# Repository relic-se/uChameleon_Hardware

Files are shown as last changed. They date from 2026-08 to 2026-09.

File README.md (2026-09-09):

# μChameleon Hardware
Digital guitar effects pedal designed around the Raspberry Pi Pico 2 and the TLC320AIC3204.

| 3D Enclosure | PCB Top | PCB Bottom |
|-|-|-|
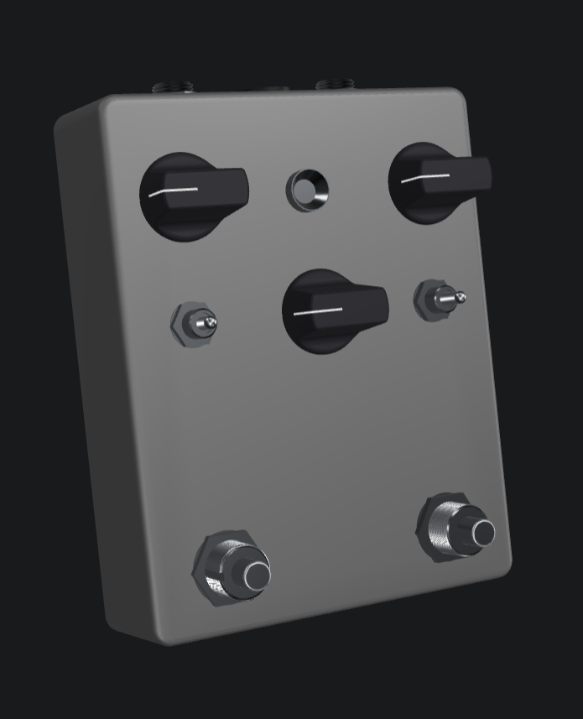
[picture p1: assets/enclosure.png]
3D rendering of μChameleon assembled enclosure
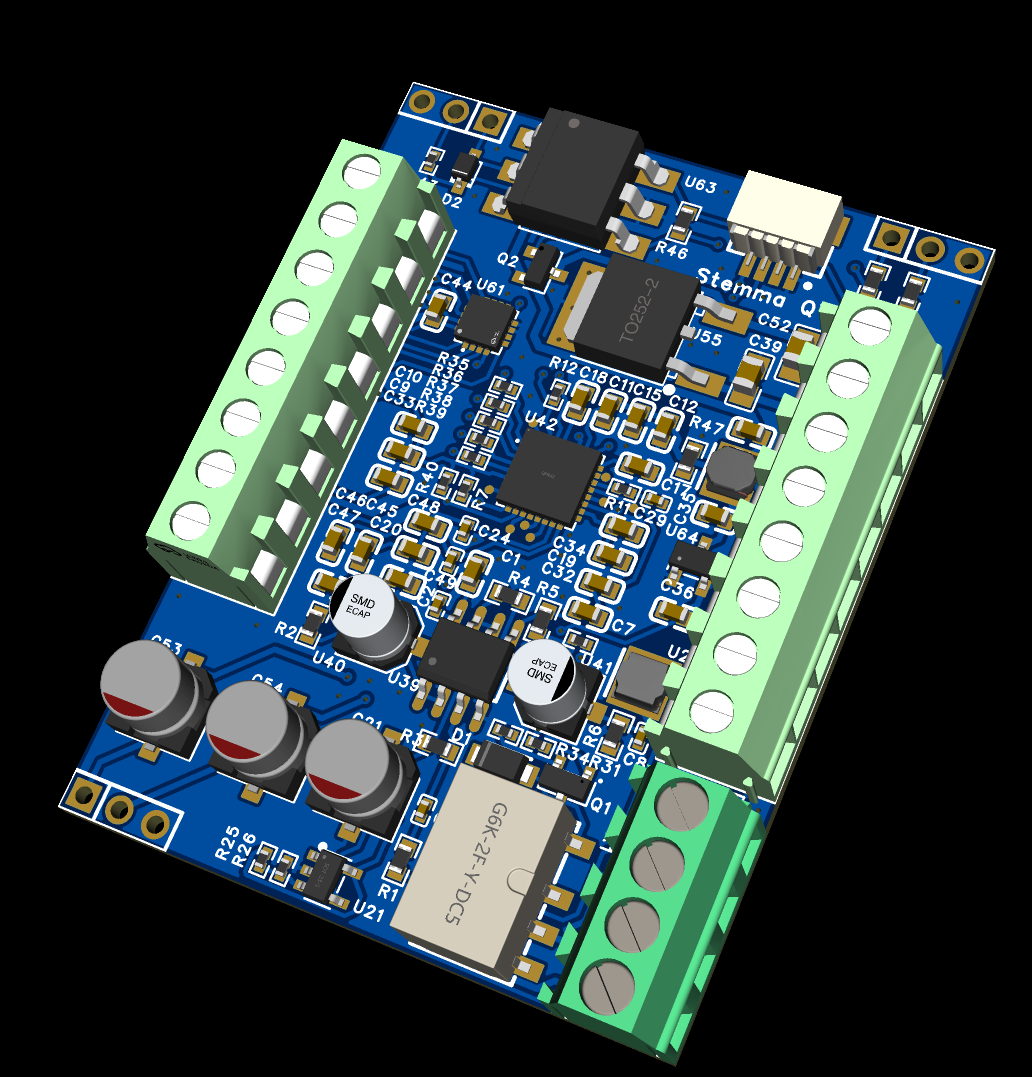
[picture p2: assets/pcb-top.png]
3D rendering of the top of the μChameleon PCB
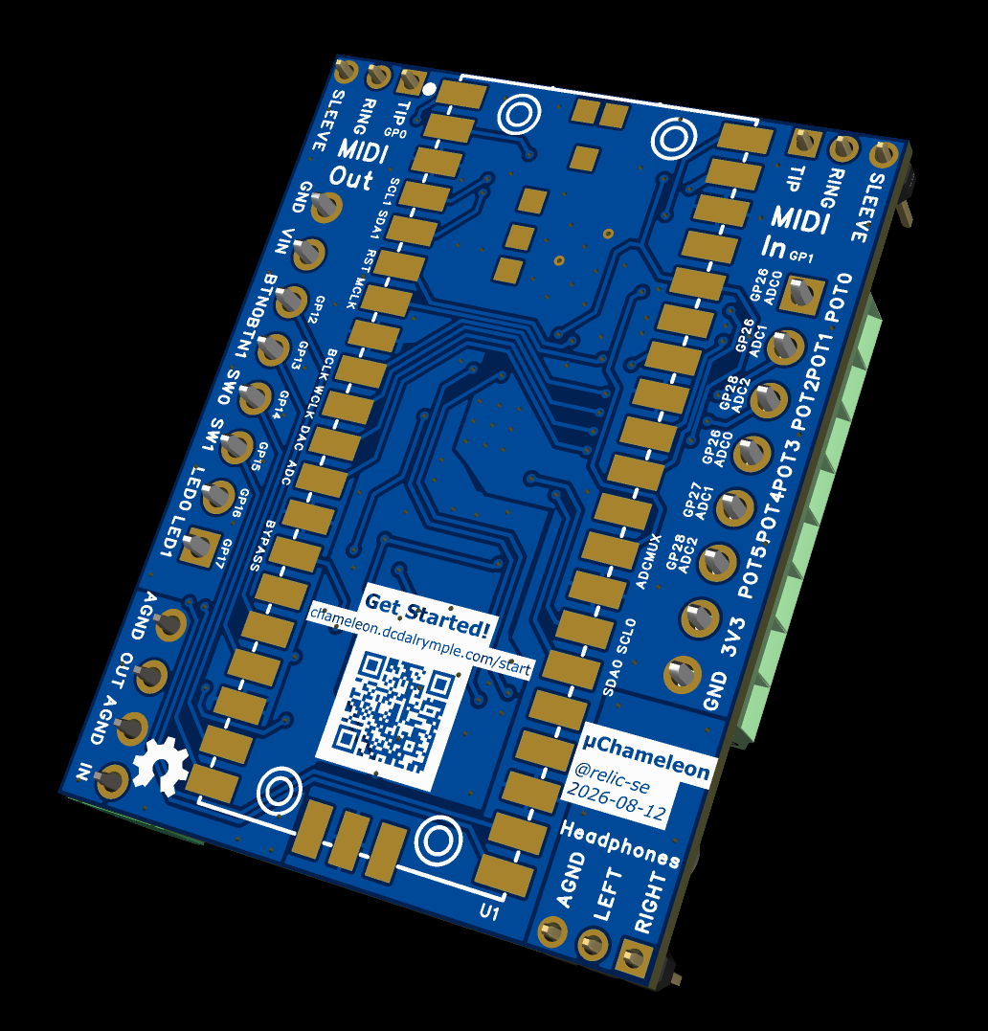
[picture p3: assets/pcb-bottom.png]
3D rendering of the bottom of the μChameleon PCB without a Raspberry Pi Pico 2
|  |  | 

## Software

- [CircuitPython Firmware](https://github.com/relic-se/uChameleon_CircuitPython)
- Arduino Firmware _(planned)_

## GPIO Configuration

The following table defines the pin configuration for the Raspberry Pi Pico (1 or 2) device.

| Pin | Function | Name | Description |
|-----|---|---|---|
| GP0 | UART | MIDI_OUT | MIDI output at 31.25 kHz |
| GP1 | UART | MIDI_IN | Opto-isolated MIDI input at 31.25 kHz |
| GP2 | I2C | SDA1 | STEMMA QT data input/output |
| GP3 | I2C | SCL1 | STEMMA QT clock |
| GP4 | GPIO | RST | Codec reset output _(active low)_ |
| GP5 | I2S | MCLK | Master clock |
| GP6 | I2S | BCLK | Bit clock |
| GP7 | I2S | WCLK | Word clock |
| GP8 | I2S | DIN | Digital audio data (DAC) |
| GP9 | I2S | DOUT | Digital audio data (ADC) |
| GP10 | GPIO | BYPASS | Preamp true bypass output _(active low)_ |
| GP11 | _Unused_ | | |
| GP12 | GPIO | BTN0 | Left footswitch button input |
| GP13 | GPIO | BTN1 | Right footswitch button input |
| GP14 | GPIO | SW0 | Left toggle switch input |
| GP15 | GPIO | SW1 | Right toggle switch input |
| GP16 | PWM | LED0 | Primary led indicator output |
| GP17 | PWM | LED1 | Secondary led indicator output |
| GP18 | _Unused_ | | |
| GP19 | _Unused_ | | |
| GP20 | I2C | SDA0 | Codec control data input/output |
| GP21 | I2C | SCL0 | Codec control clock |
| GP22 | GPIO | MUX | ADC multiplexer bank switch output _(active high)_ |
| GP26 | ADC | ADC0 | Input for POT0/3 |
| GP27 | ADC | ADC1 | Input for POT1/4 |
| GP28 | ADC | ADC2 | Input for POT2/5 |

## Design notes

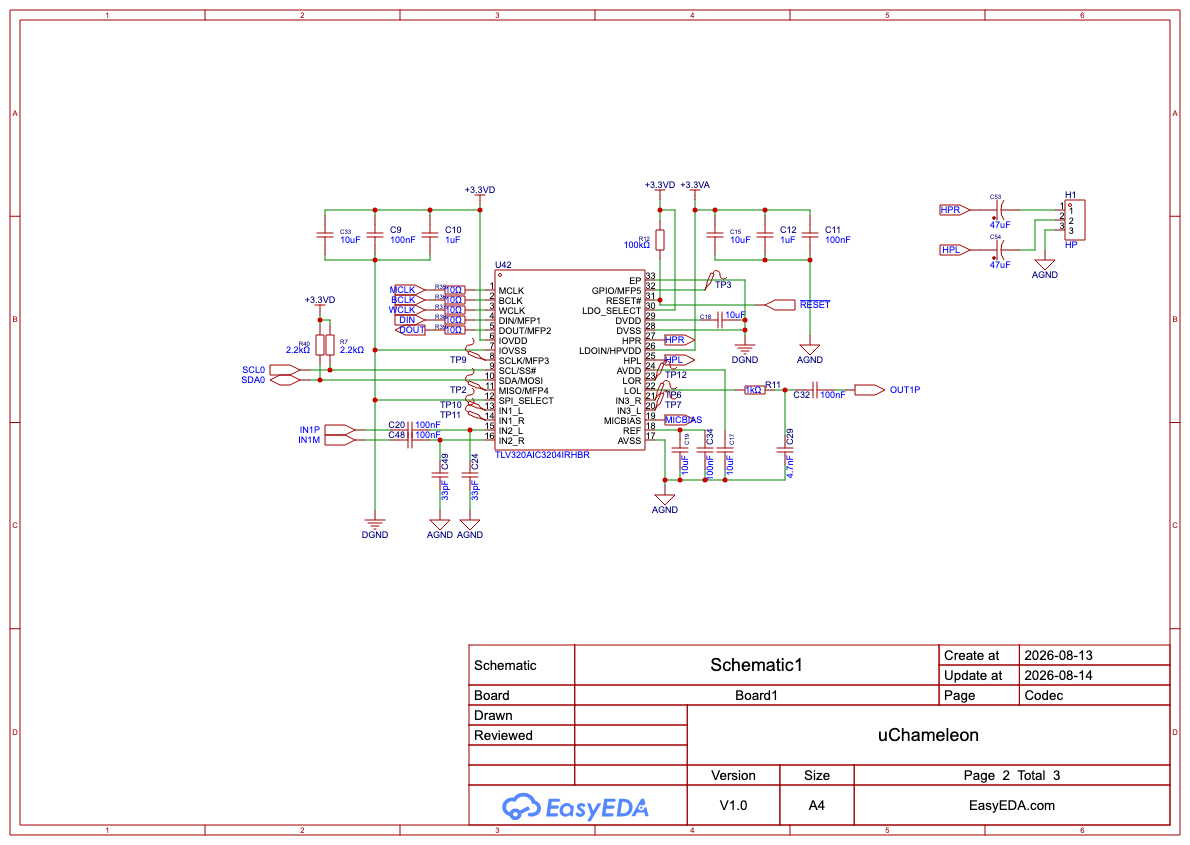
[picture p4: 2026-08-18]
pcb/schematic-2_codec.png

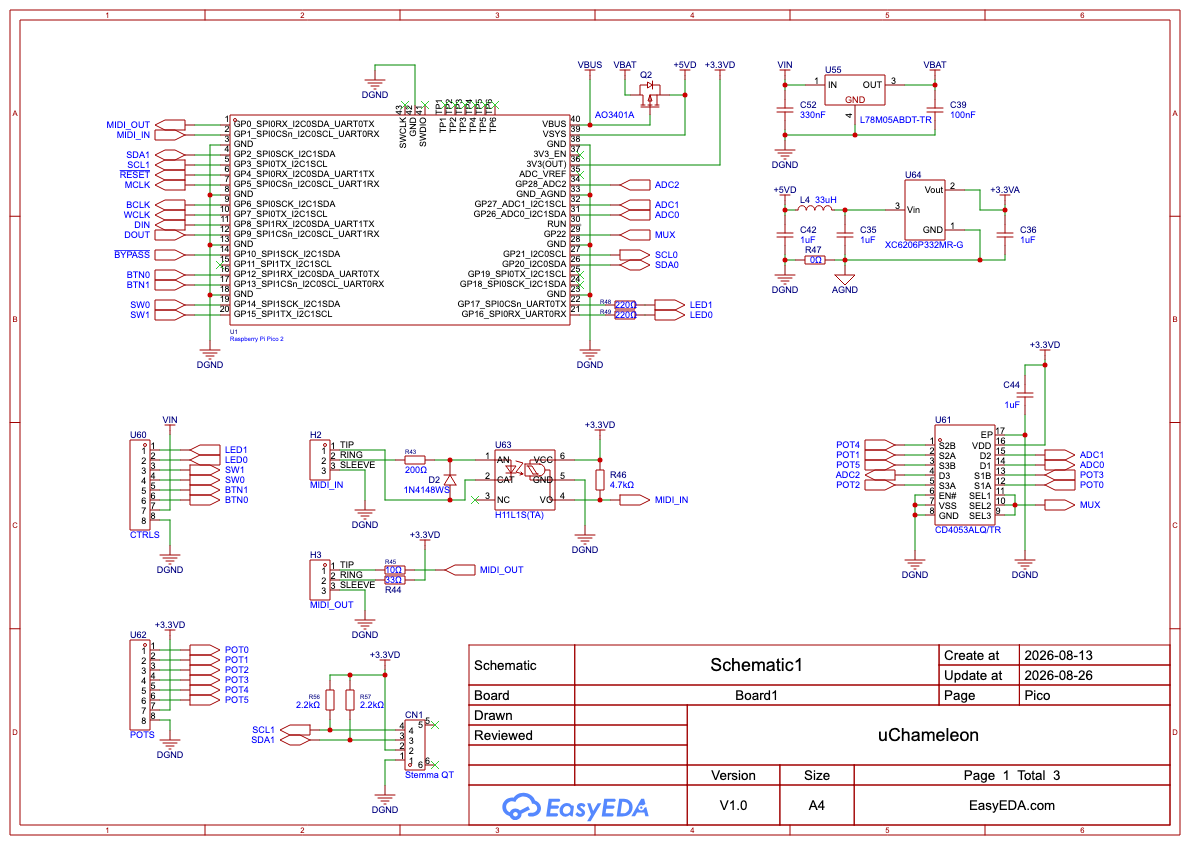
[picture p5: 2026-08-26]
pcb/schematic-1_pico.png

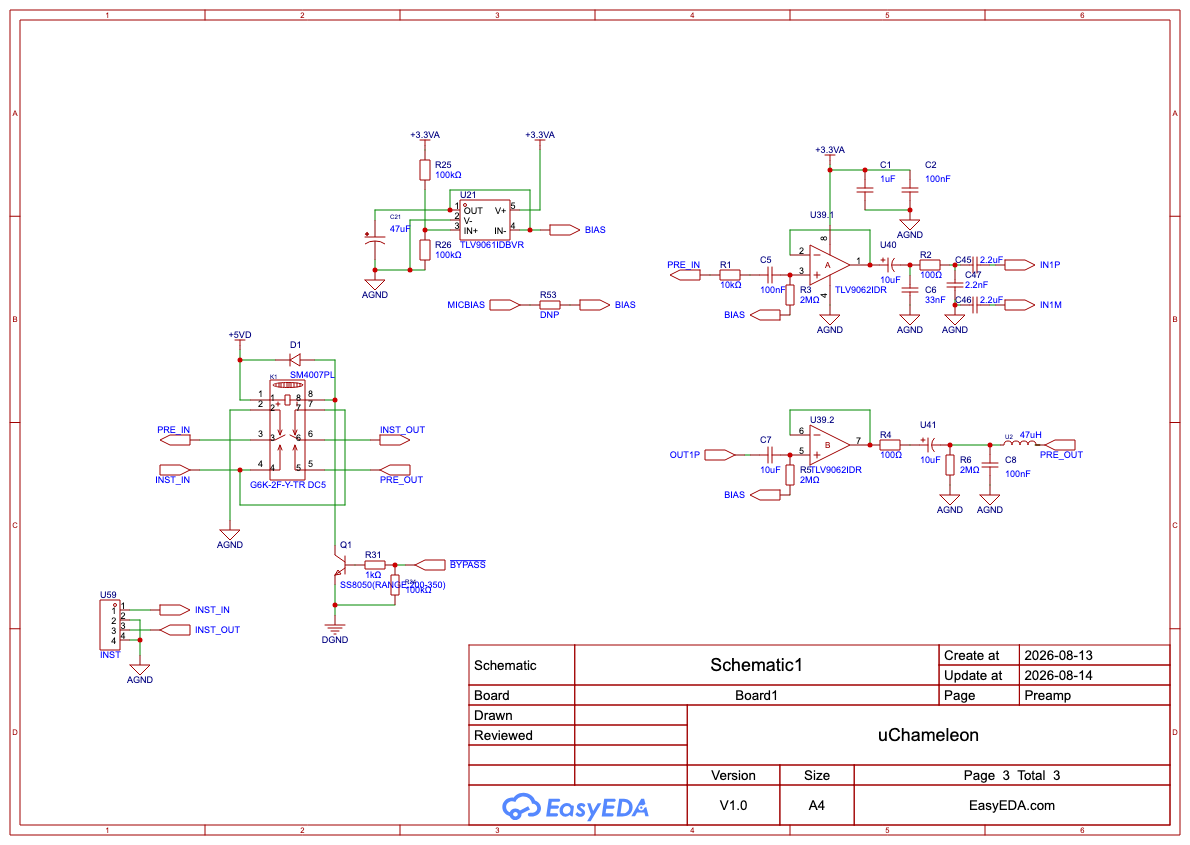
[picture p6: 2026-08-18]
pcb/schematic-3_preamp.png

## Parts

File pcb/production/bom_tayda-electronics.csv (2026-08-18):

sku | product_name | qty
A-4567 | Mini Toggle Switch SPDT On-On | 2
A-6794 | Davies 1510 Clone White Knob D Shaft 6x4.5mm | 3
A-3231 | 10K OHM Linear Taper Potentiometer D Shaft PC Mount | 3
A-2371 | SPST Momentary Soft Touch Short Shaft Push Button Stomp Foots / Pedal Switch | 2
A-661 | 3mm Bezel LED Holder Chrome Metal | 1
A-261 | LED 3mm Red | 1
A-1656 | DC Power Jack 2.1mm Enclosed Frame With Switch White | 1
A-6040 | 6.35mm 1/4" MONO Phone Jack | 2
A-5164 | 1590BB Style Aluminum Diecast Enclosure | 1

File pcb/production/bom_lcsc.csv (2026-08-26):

No. | Quantity | Comment | Designator | Footprint | Value | Manufacturer Part | Manufacturer | Supplier Part | Supplier
1 | 7 | 1uF | C1,C10,C12,C35,C36,C42,C44 | C0603 | 1uF | CL10A105KB8NNNC | SAMSUNG(三星) | C15849 | LCSC
2 | 3 | 100nF | C2,C5,C8 | C0402 | 100nF | CL05B104KO5NNNC | SAMSUNG(三星) | C1525 | LCSC
3 | 1 | 33nF | C6 | C0603 | 33nF | CL10B333KB8NNNC | SAMSUNG(三星) | C21117 | LCSC
4 | 6 | 10uF | C7,C15,C17,C18,C19,C33 | C0603 | 10uF | CL10A106MA8NRNC | SAMSUNG(三星) | C96446 | LCSC
5 | 6 | 100nF | C9,C11,C20,C32,C34,C48 | C0603 | 100nF | CC0603KRX7R9BB104 | YAGEO(国巨) | C14663 | LCSC
6 | 3 | 47uF | C21,C53,C54 | CAP-SMD_BD5.0-L5.3-W5.3-LS6.0-FD | 47uF | EFVH025ADA470M0554 | FOLLON(富隆电子) | C22387973 | LCSC
7 | 2 | 33pF | C24,C49 | C0402 | 33pF | 0402CG330J500NT | FH(风华) | C1562 | LCSC
8 | 1 | 4.7nF | C29 | C0402 | 4.7nF | 0402B472K500NT | FH(风华) | C1538 | LCSC
9 | 1 | 100nF | C39 | C0805 | 100nF | CC0805KRX7R9BB104 | YAGEO(国巨) | C49678 | LCSC
10 | 2 | 2.2uF | C45,C46 | C0603 | 2.2uF | CL10A225KO8NNNC | SAMSUNG(三星) | C23630 | LCSC
11 | 1 | 2.2nF | C47 | C0603 | 2.2nF | 0603B222K500NT | FH(风华) | C1604 | LCSC
12 | 1 | 330nF | C52 | C0805 | 330nF | 08053C334K4Z2A | Kyocera AVX | C273671 | LCSC
13 | 1 | Stemma QT | CN1 | CONN-SMD_4P-P1.00_XY-SM04B-SRSS-TB |  | Stemma QT | XYECONN(辛译) | C51940130 | LCSC
14 | 1 | SM4007PL | D1 | SOD-123F_L2.8-W1.8-LS3.7-RD |  | SM4007PL | MDD(辰达半导体) | C64898 | LCSC
15 | 1 | 1N4148WS | D2 | SOD-323_L1.8-W1.3-LS2.5-RD |  | 1N4148WS | CJ(江苏长电/长晶) | C2128 | LCSC
16 | 1 | HP | H1 | HDR-TH_3P-P2.54-V-M
17 | 1 | MIDI_IN | H2 | HDR-TH_3P-P2.54-V-M
18 | 1 | MIDI_OUT | H3 | HDR-TH_3P-P2.54-V-M
19 | 1 | G6K-2F-Y-TR DC5 | K1 | RELAY-SMD_G6K-2F-X-XX |  | G6K-2F-Y-TR DC5 | OMRON(欧姆龙) | C47190 | LCSC
20 | 1 | 33uH | L4 | IND-SMD_L3.1-W3.1 | 33uH | SQH3010S-330M-LF | Coilmaster(统宇电研) | C257160 | LCSC
21 | 1 | SS8050(RANGE:200-350) | Q1 | SOT-23-3_L3.0-W1.3-P1.90-LS2.5-BR |  | SS8050(RANGE:200-350) | CJ(江苏长电/长晶) | C2150 | LCSC
22 | 1 | AO3401A | Q2 | SOT-23-3_L2.9-W1.3-P0.95-LS2.4-BR-1 |  | AO3401A | AOS | C15127 | LCSC
23 | 1 | 10kΩ | R1 | R0603 | 10kΩ | 0603WAF1002T5E | UNI-ROYAL(厚声) | C25804 | LCSC
24 | 2 | 100Ω | R2,R4 | R0603 | 100Ω | 0603WAF1000T5E | UNI-ROYAL(厚声) | C22775 | LCSC
25 | 3 | 2MΩ | R3,R5,R6 | R0603 | 2MΩ | 0603WAF2004T5E | UNI-ROYAL(厚声) | C22976 | LCSC
26 | 4 | 2.2kΩ | R7,R40,R56,R57 | R0402 | 2.2kΩ | 0402WGF2201TCE | UNI-ROYAL(厚声) | C25879 | LCSC
27 | 2 | 1kΩ | R11,R31 | R0402 | 1kΩ | 0402WGF1001TCE | UNI-ROYAL(厚声) | C11702 | LCSC
28 | 4 | 100kΩ | R12,R25,R26,R34 | R0402 | 100kΩ | 0402WGF1003TCE | UNI-ROYAL(厚声) | C25741 | LCSC
29 | 5 | 10Ω | R35,R36,R37,R38,R39 | R0402 | 10Ω | 0402WGF100JTCE | UNI-ROYAL(厚声) | C25077 | LCSC
30 | 1 | 200Ω | R43 | R0402 | 200Ω | 0402WGF2000TCE | UNI-ROYAL(厚声) | C25087 | LCSC
31 | 1 | 33Ω | R44 | R0603 | 33Ω | 0603WAF330JT5E | UNI-ROYAL(厚声) | C23140 | LCSC
32 | 1 | 10Ω | R45 | R0603 | 10Ω | 0603WAF100JT5E | UNI-ROYAL(厚声) | C22859 | LCSC
33 | 1 | 4.7kΩ | R46 | R0603 | 4.7kΩ | 0603WAF4701T5E | UNI-ROYAL(厚声) | C23162 | LCSC
34 | 1 | 0Ω | R47 | R0603 | 0Ω | 0603WAF0000T5E | UNI-ROYAL(厚声) | C21189 | LCSC
35 | 2 | 220Ω | R48,R49 | R0402 | 220Ω | 0402WGF2200TCE | UNI-ROYAL(厚声) | C25091 | LCSC
36 | 1 | DNP | R53 | R0402 | DNP
37 | 8 | Test-Point | TP2,TP3,TP6,TP7,TP9,TP10,TP11,TP12 | Test-Point-0.5mm
38 | 1 | Raspberry Pi Pico 2 | U1 | COMM-SMD_L51.0-W21.0-P2.54_SC0916 |  | Raspberry Pi Pico 2 | Raspberry Pi(树莓派) | C41407547 | LCSC
39 | 1 | 47uH | U2 | IND-SMD_L3.0-W3.0-HPC3015TF-2R2M | 47uH | SNR3015TYD470M | SOREDE(索瑞达) | C2827372 | LCSC
40 | 1 | TLV9061IDBVR | U21 | SOT-23-5_L3.0-W1.7-P0.95-LS2.8-BL |  | TLV9061IDBVR | TI(德州仪器) | C398358 | LCSC
41 | 1 | TLV9062IDR | U39 | SOIC-8_L5.0-W4.0-P1.27-LS6.0-BL |  | TLV9062IDR | TI(德州仪器) | C398355 | LCSC
42 | 2 | 10uF | U40,U41 | CAP-SMD_BD4.0-L4.3-W4.3-LS5.0-FD | 10uF | RST10UF35V015 | KNSCHA(科尼盛) | C4747970 | LCSC
43 | 1 | TLV320AIC3204IRHBR | U42 | QFN-32_L5.0-W5.0-P0.50-TL-EP3.4 |  | TLV320AIC3204IRHBR | TI(德州仪器) | C24109 | LCSC
44 | 1 | L78M05ABDT-TR | U55 | TO-252-2_L6.5-W6.1-P4.58-LS10.0-TL |  | L78M05ABDT-TR | ST(意法半导体) | C58069 | LCSC
45 | 1 | INST | U59 | CONN-TH_DB125-3.5-4P-GN |  | INST | DORABO(地博电气) | C2757925 | LCSC
46 | 1 | CTRLS | U60 | CONN-TH_8P-P3.50_DORABO_DB125-3.5-8P-GN-S |  | CTRLS | DORABO(地博电气) | C5184954 | LCSC
47 | 1 | CD4053ALQ/TR | U61 | QFN-16_L3.0-W3.0-P0.50-TL-EP1.7-A |  | CD4053ALQ/TR | HGSEMI(华冠) | C50703794 | LCSC
48 | 1 | POTS | U62 | CONN-TH_8P-P3.50_DORABO_DB125-3.5-8P-GN-S |  | POTS | DORABO(地博电气) | C5184954 | LCSC
49 | 1 | H11L1S(TA) | U63 | SMD-6_L7.3-W6.5-P2.54-LS10.2-BL |  | H11L1S(TA) | EVERLIGHT(亿光) | C78589 | LCSC
50 | 1 | XC6206P332MR-G | U64 | SOT-23-3_L2.9-W1.6-P1.90-LS2.8-BR |  | XC6206P332MR-G | TOREX(特瑞仕) | C5446 | LCSC

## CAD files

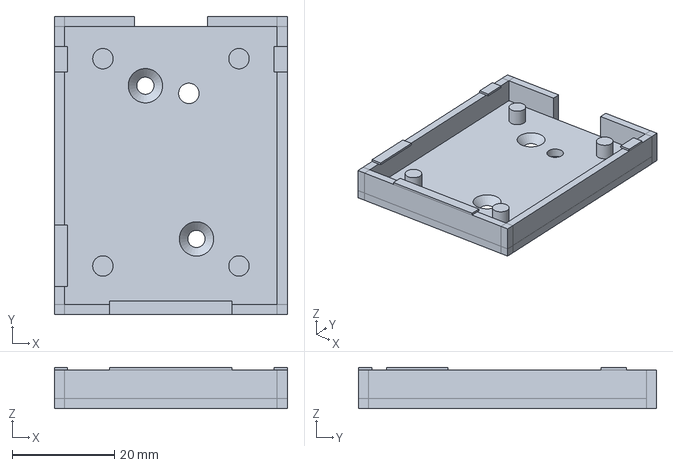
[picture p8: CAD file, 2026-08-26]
assembly/pcb-holder/pcb-holder.FCStd
45.6 x 58.3 x 8.05 mm

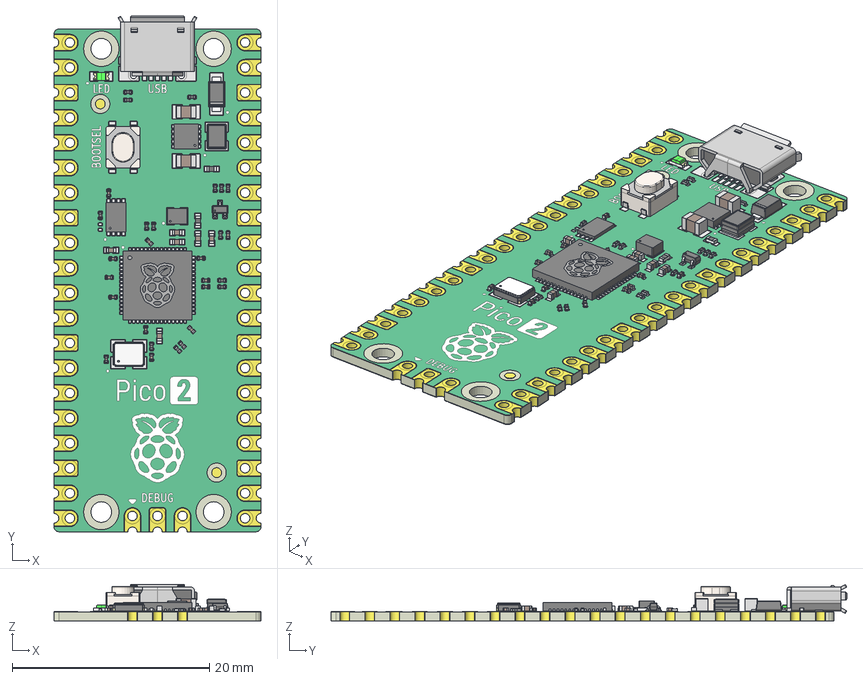
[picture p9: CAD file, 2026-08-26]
assembly/pcb-holder/rpi_pico2.step
21.0 x 52.3 x 3.77 mm
CapacitorMainBody x 21
CapacitorContacts x 21
ResistorMainBody x 17
ResistorBlackLayer x 17
ResistorContacts x 17
Pins x 7
Package x 5
EP x 3
Pin1Indicator x 5
Logo
Chassis
Contacts x 3
Back
CathodeIndicator
Lid
Pads
PinIndicator
White_Body
Lens
Plastic_Body
Metal_Plate
Plastic_Plunger
rpi_pico2_PCB

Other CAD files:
assembly/pcb-holder/pcb-holder.stl

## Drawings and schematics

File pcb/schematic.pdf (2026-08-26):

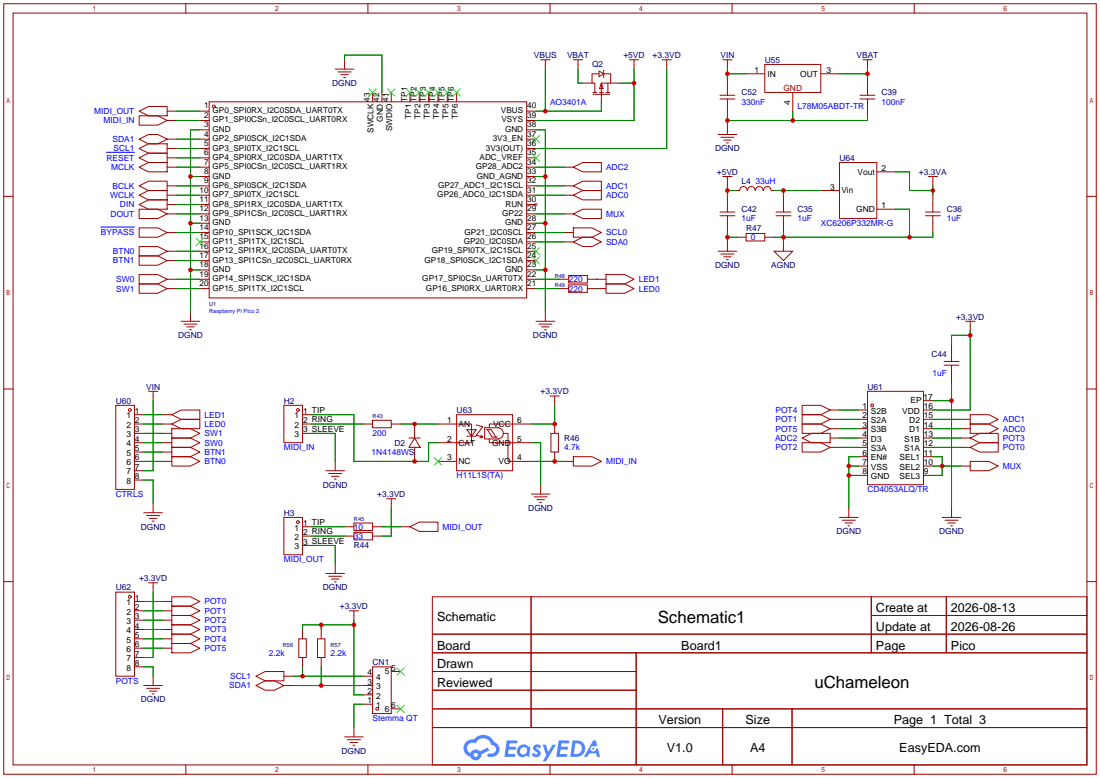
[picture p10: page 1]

Schematic | Schematic1 | Create at | 2026-08-13

Update at | 2026-08-26

Board | Board1 | Page | Pico
Drawn | | uChameleon
Reviewed

Version | Size | Page 1 Total 3
V1.0 | A4 | EasyEDA.com

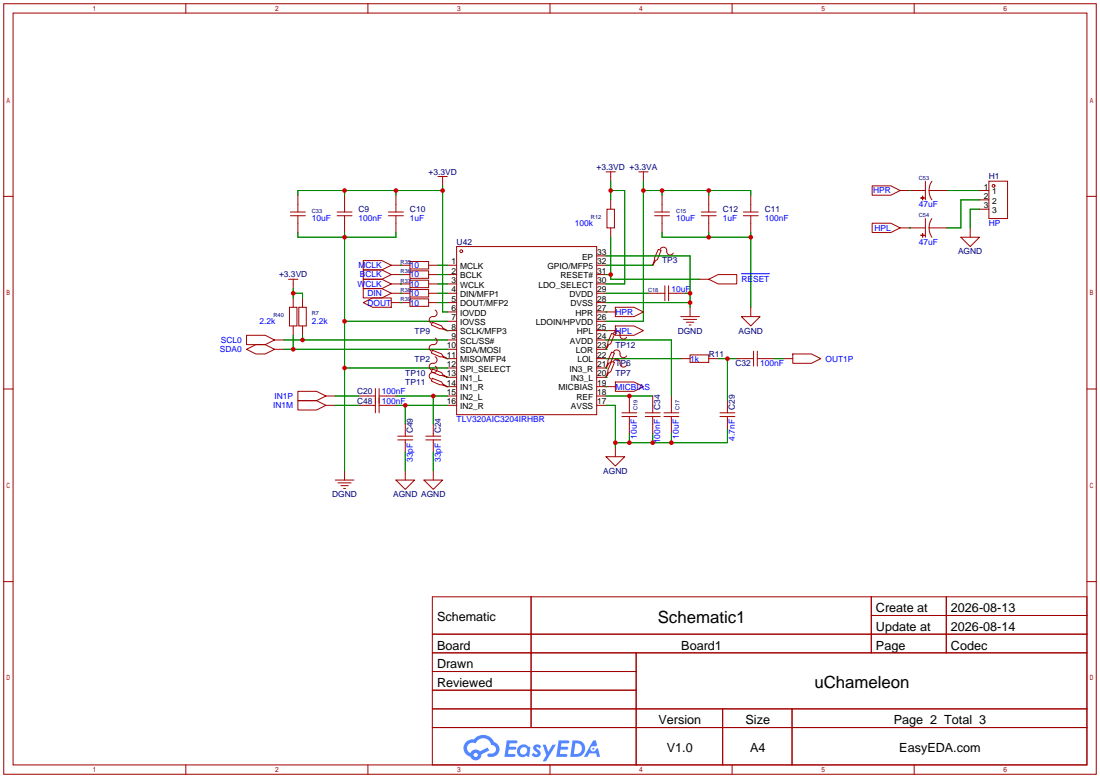
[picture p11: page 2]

Schematic | Schematic1 | Create at | 2026-08-13

Update at | 2026-08-14

Board | Board1 | Page | Codec
Drawn | | uChameleon
Reviewed

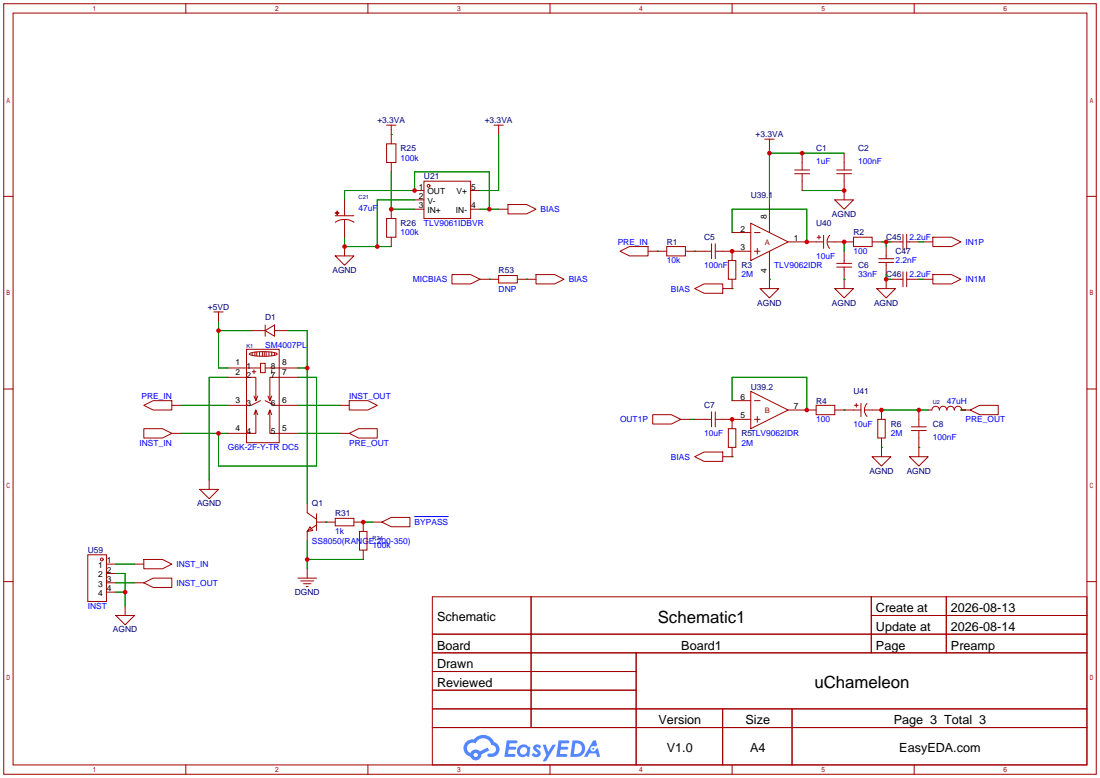
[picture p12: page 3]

Schematic | Schematic1 | Create at | 2026-08-13

Update at | 2026-08-14

Board | Board1 | Page | Preamp
Drawn | | uChameleon
Reviewed

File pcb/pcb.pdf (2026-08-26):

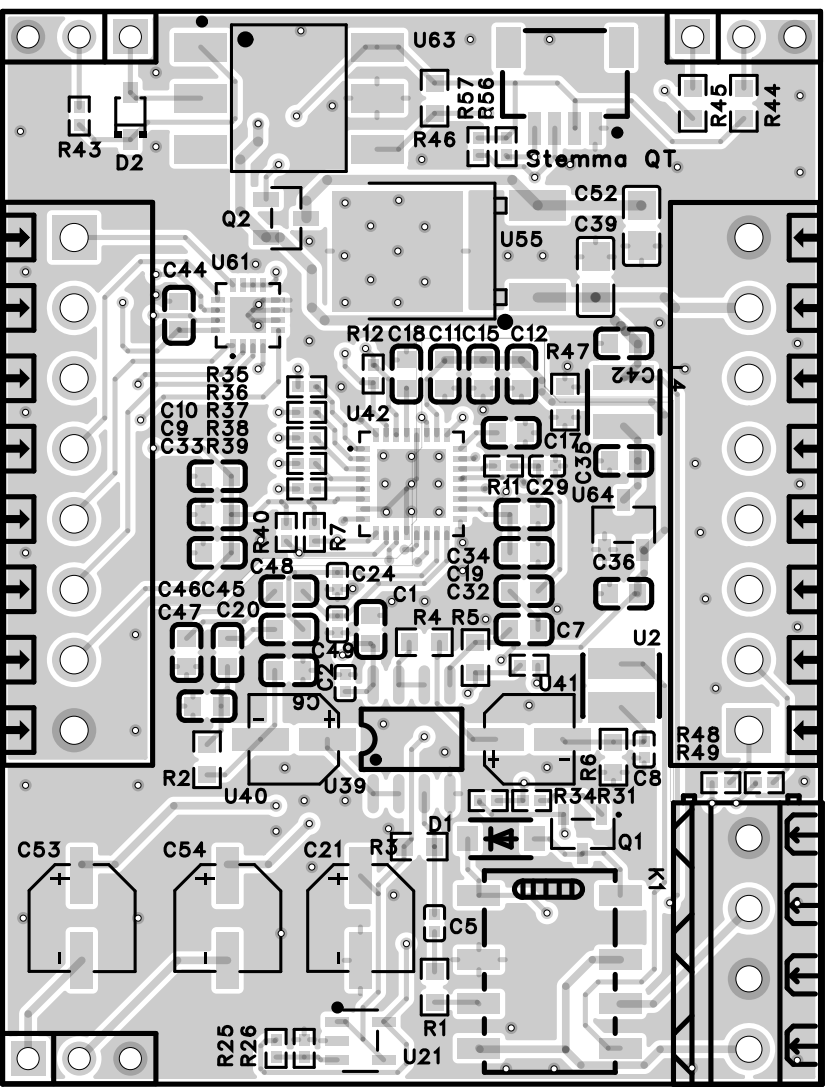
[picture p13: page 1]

## MIDI Out

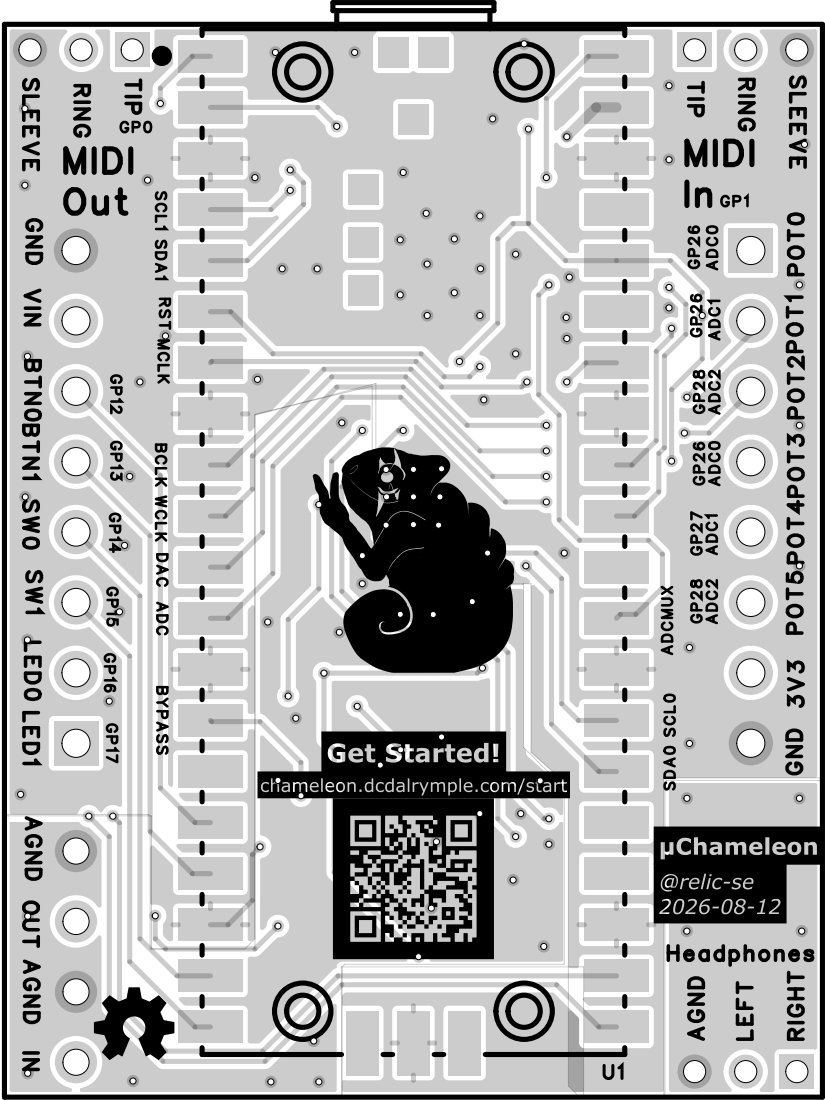
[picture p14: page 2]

BYPASS ADC DAC WCLK BCLK MCLK RST SCL1 SDA1

AGND AGND IN OUT LED1 LED0 SW1 SW0 BTN1 BTN0 VIN GND

chameleon.dcdalrymple.com/start

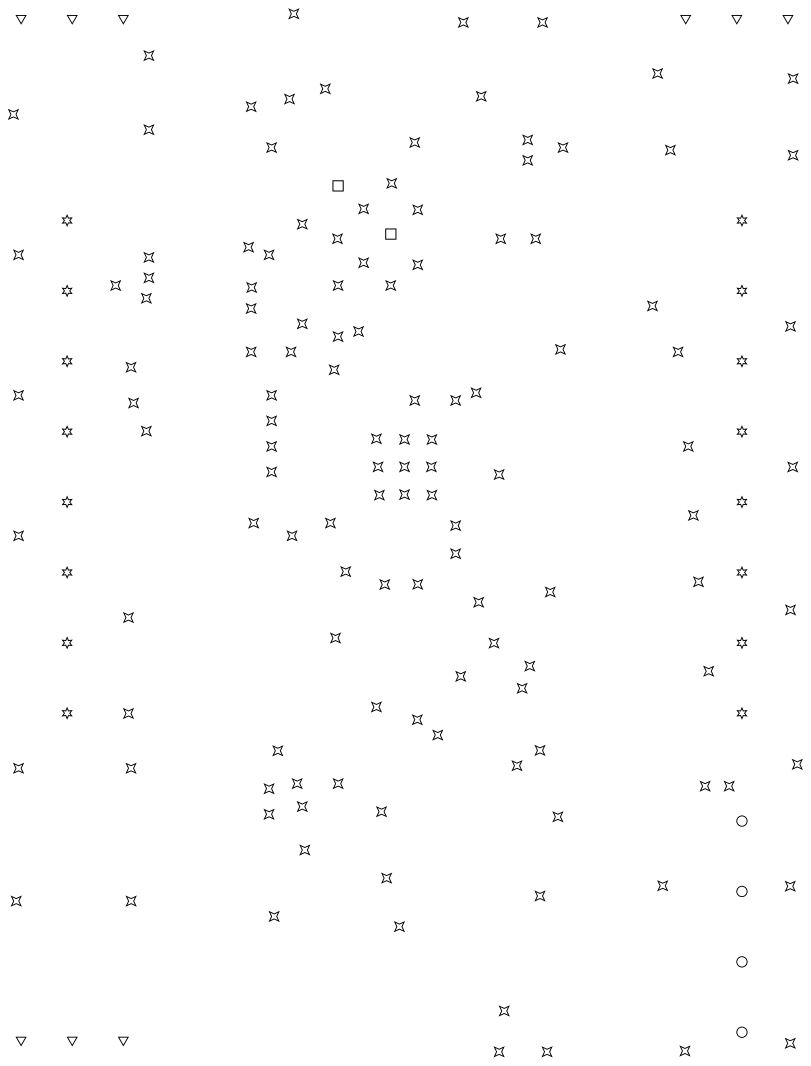
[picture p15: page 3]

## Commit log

2026-08-18 Add faceplates and drill guide
2026-08-18 Add PCB files and assets
    [bom_lcsc.csv, bom_tayda-electronics.csv, pickandplace_jlcpcb.xlsx]
2026-08-24 Reorganized laser cuts
2026-08-26 Add pcb holder model for 3d printing
    [pcb-holder.FCStd, pcb-holder.stl, rpi_pico2.step]
2026-08-26 Fix missing pull up resistors on stemma qt port
    [bom_lcsc.csv, pickandplace_jlcpcb.xlsx]
2026-08-26 Improve pcb holder
    [pcb-holder.FCStd, pcb-holder.stl]
2026-08-26 Fix reversed SDA/SCL on stemma qt
    [pickandplace_jlcpcb.xlsx]
2026-09-02 Add pitch shift faceplate
2026-09-09 Reverse i2s data naming to match arduino
2026-09-09 Fix I2C bus #
